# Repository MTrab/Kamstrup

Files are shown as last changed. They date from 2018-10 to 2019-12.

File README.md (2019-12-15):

# DOES NOT WORK ON NEWER KAMSTRUP FIRMWARE IN DENMARK [danish text follows]
Pga. GDPR er forsynings virksomhederne begyndt at lukke for IR adgang - al adgang skal fremadrettet ske via et HAN modul (f.eks. Smart-Me) og med en krypteringsnøgle som udleveres af forsynings virkesomheden, på forlangende.

# Kamstrup Multical Electrical Meter Data Extractor
This sketch is tested and fully functional on a Kamstrup Omnipower 684, but should work with the older Multical 382 meters as well

# BOM
I used these parts:
<ul>
    <li>D1/D2 TCRT5000 IR sensor: https://trab.dk/sensorer/47-ir-reflektiv-optisk-sensor.html</li>
    <li>R1 1K ohm</li>
    <li>R2 10K ohm</li>
    <li>Arduino board Nano: https://trab.dk/boards/12-nano.html</li>
</ul>

# Connection
RX pin are connected to D7 and TX pin to D6.<br>
VCC(+5v) are connected to 5V pin and GND to GND<br>
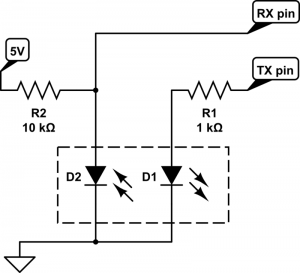
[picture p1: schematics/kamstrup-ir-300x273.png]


# Notes
I had great difficulties getting this to work with the latest board definitions in the Arduino IDE.<br>
The ones I have successfully used are versions no later than 1.6.21

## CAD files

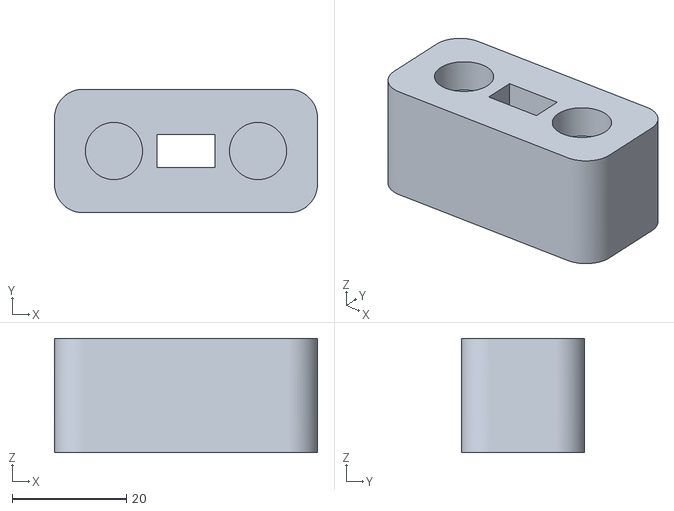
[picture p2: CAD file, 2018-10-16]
stl/IR-Eye-Body.stl
46.0 x 21.6 x 20.0

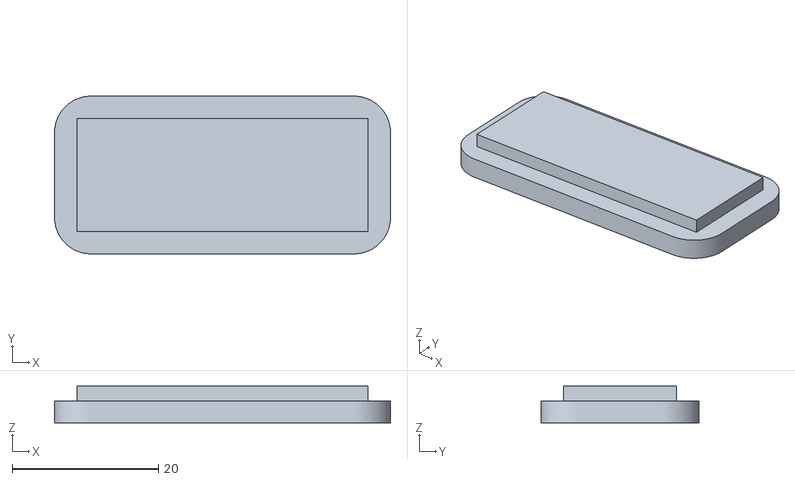
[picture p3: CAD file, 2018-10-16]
stl/IR-Eye-Lid.stl
46.0 x 21.6 x 5.00

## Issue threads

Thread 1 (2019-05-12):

Hal9k IR og Arduino UNO

tsvane, 2019-05-12:
Hej Morten.

Jeg har brugt det meste af weekenden på at få dit projekt til at køre på min Arduino UNO (rev 3e) og Hal9k IR modul ([https://wiki.hal9k.dk/projects/kamstrup](https://wiki.hal9k.dk/projects/kamstrup)) sammen med min Kamstrup Omnipower el-måler. Men uden held. Skulle der være nogen åbenlyse komplikationer i dette setup? Jeg er rimlig ny til det her med Arduino, så det kan være jeg er helt på vildspor.

Jeg har forsøgt mig med at tilføje en serial.print med rxindex for at se om der overhovedet bliver modtaget noget data, men denne er altid 0 når IR-modulet sidder på måleren.
Men hvis jeg tager en fjernbetjening og peger mod RX-dioden viser den fint at der modtages data. Ligeledes kan jeg konstatere at TX-dioden lyser når jeg ser på den med et kamera.

Kan det være at måleren har fået slået IR-interfacet fra?

Med venlig hilsen
Tobias

MTrab, 2019-05-12:
Jeg har selv forsøgt med Hal9k's modul og har aldrig fået det til at virke.
Bl.a. derfor jeg har lavet dette forsimplet setup, som virker.

Men igen - denne kode er ikke kompatibel med Hal9k's modul, det er helt udelukket.

tsvane, 2019-05-12:
OK, tak for hurtigt svar :)

anderssvante, 2019-05-12:
Hej Morten
Jeg har også forsøgt mig med både [HAL9k og din løsning uden held](https://forum.arduino.cc/index.php?topic=596890.0).
Det tætteste jeg kom på noget, der lignede en respons, var:
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

Jeg kan ikke lige lure hvad opkastet efter "Current power" er? Samt hvorfor alle værdier er nul.
Du skriver at du havde besværligheder med boarddefinitionerne - hvad gik dét på?

mvh Anders

MTrab, 2019-05-12:
Det ligner du er udsat for det samme som jeg er blevet.
Aura har deaktiveret IR interfacet her i området hvor jeg bor.

Min begyndte at skrive som din, og jeg har derfor snakket med Aura, som har deaktiveret IR interface som følge af GDPR - det bliver ikke aktiveret igen, desværre.

anderssvante, 2019-05-12:
Takker. Så giver det ikke meget mening, at kaste flere arbejdstimer efter at prøve at få det til at virke.

Closed 2019-05-12.

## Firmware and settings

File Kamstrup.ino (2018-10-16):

/*
 * Made by Morten Trab - 2018
 * 
 * Code adapted and cleaned from http://www.kildal.dk/forbrugsdata/elmaler-arduino-kode/
 *  
 */
 
#include <SoftwareSerialInverted.h>
#include <SPI.h>
#include <avr/wdt.h>

// Kamstrup registers
word const kamnums[] = { 0x0001,0x03ff,0x041e,0x041f,0x0420,0x0002,0x0434,0x0435,0x0436,0x0438,0x0439,0x043a };
char* kamstrings[]   = { "Energy in","Current Power","Voltage p1","Voltage p2","Voltage p3","Energy out","Current p1","Current p2","Current p3","Power p1","Power p2","Power p3" };
#define KAMNUMREGS 12

// Units
char*  units[65] = {"","Wh","kWh","MWh","GWh","j","kj","Mj",
	"Gj","Cal","kCal","Mcal","Gcal","varh","kvarh","Mvarh","Gvarh",
        "VAh","kVAh","MVAh","GVAh","kW","kW","MW","GW","kvar","kvar","Mvar",
        "Gvar","VA","kVA","MVA","GVA","V","A","kV","kA","C","K","l","m3",
        "l/h","m3/h","m3xC","ton","ton/h","h","hh:mm:ss","yy:mm:dd","yyyy:mm:dd",
        "mm:dd","","bar","RTC","ASCII","m3 x 10","ton x 10","GJ x 10","minutes","Bitfield",
        "s","ms","days","RTC-Q","Datetime"};

// Pin definitions
#define PIN_KAM_RX 7  // D7 to Kamstrup IR interface RX
#define PIN_KAM_TX 6  // D6 to Kamstrup IR interface TX

// Kamstrup optical IR serial
#define KAMTIMEOUT 300  // Kamstrup timeout after transmit
#define KAMBAUD 9600    // Kamstrup baud rate
SoftwareSerial kamSer(PIN_KAM_RX, PIN_KAM_TX, true);  // Initialize serial

void setup() {
  // setup pins
  pinMode(PIN_KAM_RX,INPUT);
  pinMode(PIN_KAM_TX,OUTPUT);
    
  
  // initialize serial interface
  Serial.begin(115200);
  
  kamSer.begin(KAMBAUD);
}

void loop() {
  Serial.println("-- Aflæser Kamstrup Elmåler --");  
  for (int kreg = 0; kreg < KAMNUMREGS; kreg++) {
    kamReadReg(kreg);
  }
  delay(2000);
};

// kamReadReg - read a Kamstrup register
void kamReadReg(unsigned short kreg) {

  byte recvmsg[30];  // buffer of bytes to hold the received data
  float rval;        // this will hold the final value

  // prepare message to send and send it
  byte sendmsg[] = { 0x3f, 0x10, 0x01, (kamnums[kreg] >> 8), (kamnums[kreg] & 0xff) };
  kamSend(sendmsg, 5);

  // listen if we get an answer
  unsigned short rxnum = kamReceive(recvmsg);

  // check if number of received bytes > 0 
  if(rxnum != 0){
    
    // decode the received message
    rval = kamDecode(kreg,recvmsg);
    
    // print out received value to terminal (debug)
    Serial.print(kamstrings[kreg]);
    Serial.print(": ");
    Serial.print(rval);
    Serial.print(" ");
    Serial.println(units[recvmsg[4]]);
  }
}

// kamSend - send data to Kamstrup meter
void kamSend(byte const *msg, int msgsize) {

  // append checksum bytes to message
  byte newmsg[msgsize+2];
  for (int i = 0; i < msgsize; i++) { newmsg[i] = msg[i]; }
  newmsg[msgsize++] = 0x00;
  newmsg[msgsize++] = 0x00;
  int c = crc_1021(newmsg, msgsize);
  newmsg[msgsize-2] = (c >> 8);
  newmsg[msgsize-1] = c & 0xff;

  // build final transmit message - escape various bytes
  byte txmsg[20] = { 0x80 };   // prefix
  int txsize = 1;
  for (int i = 0; i < msgsize; i++) {
    if (newmsg[i] == 0x06 or newmsg[i] == 0x0d or newmsg[i] == 0x1b or newmsg[i] == 0x40 or newmsg[i] == 0x80) {
      txmsg[txsize++] = 0x1b;
      txmsg[txsize++] = newmsg[i] ^ 0xff;
    } else {
      txmsg[txsize++] = newmsg[i];
    }
  }
  txmsg[txsize++] = 0x0d;  // EOF

  // send to serial interface
  for (int x = 0; x < txsize; x++) {
    kamSer.write(txmsg[x]);
  }

}

// kamReceive - receive bytes from Kamstrup meter
unsigned short kamReceive(byte recvmsg[]) {

  byte rxdata[50];  // buffer to hold received data
  unsigned long rxindex = 0;
  unsigned long starttime = millis();
  
  kamSer.flush();  // flush serial buffer - might contain noise

  byte r;
  
  // loop until EOL received or timeout
  while(r != 0x0d){
    
    // handle rx timeout
    if(millis()-starttime > KAMTIMEOUT) {
      Serial.println("Timed out listening for data");
      return 0;
    }

    // handle incoming data
    if (kamSer.available()) {

      // receive byte
      r = kamSer.read();
      if(r != 0x40) {  // don't append if we see the start marker
        // append data
        rxdata[rxindex] = r;
        rxindex++; 
      }

    }
  }

  // remove escape markers from received data
  unsigned short j = 0;
  for (unsigned short i = 0; i < rxindex -1; i++) {
    if (rxdata[i] == 0x1b) {
      byte v = rxdata[i+1] ^ 0xff;
      if (v != 0x06 and v != 0x0d and v != 0x1b and v != 0x40 and v != 0x80){
        Serial.print("Missing escape ");
        Serial.println(v,HEX);
      }
      recvmsg[j] = v;
      i++; // skip
    } else {
      recvmsg[j] = rxdata[i];
    }
    j++;
  }
  
  // check CRC
  if (crc_1021(recvmsg,j)) {
    Serial.println("CRC error: ");
    return 0;
  }
  
  return j;
  
}

// kamDecode - decodes received data
float kamDecode(unsigned short const kreg, byte const *msg) {
  // skip if message is not valid
  if (msg[0] != 0x3f or msg[1] != 0x10) {
    return false;
  }
  if (msg[2] != (kamnums[kreg] >> 8) or msg[3] != (kamnums[kreg] & 0xff)) {
    return false;
  }
    
  // decode the mantissa
  long x = 0;
  for (int i = 0; i < msg[5]; i++) {
    x <<= 8;
    x |= msg[i + 7];
  }
  
  // decode the exponent
  int i = msg[6] & 0x3f;
  if (msg[6] & 0x40) {
    i = -i;
  };
  float ifl = pow(10,i);
  if (msg[6] & 0x80) {
    ifl = -ifl;
  }

  // return final value
  return (float )(x * ifl);

}

// crc_1021 - calculate crc16
long crc_1021(byte const *inmsg, unsigned int len){
  long creg = 0x0000;
  for(unsigned int i = 0; i < len; i++) {
    int mask = 0x80;
    while(mask > 0) {
      creg <<= 1;
      if (inmsg[i] & mask){
        creg |= 1;
      }
      mask>>=1;
      if (creg & 0x10000) {
        creg &= 0xffff;
        creg ^= 0x1021;
      }
    }
  }
  return creg;
}

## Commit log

2019-01-15 My current MySensors sketch
2019-01-21 Wrong link to the TCRT5000 sensor
